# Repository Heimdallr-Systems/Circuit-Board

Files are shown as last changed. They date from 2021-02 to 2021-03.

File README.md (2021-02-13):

# Circuit-Board

Custom Power and IO board for the robot

## Folders

### CapsoneParts.3dshapes

Custom 3D models for KiCAD

### CapsstoneParts.pretty

Custom footprints for KiCAD

### optionalParts

Schematics of circuits that might be added to the main PCB

### Simulations/TINA-TI

[TINA-TI](https://www.ti.com/tool/TINA-TI) simulations used during design

### Simulations/LTspice

[LTspice](https://www.analog.com/en/design-center/design-tools-and-calculators/ltspice-simulator.html) simulations used
during design process

### TPS55288RPMR

Files used to make the TPS55288 components for KiCAD

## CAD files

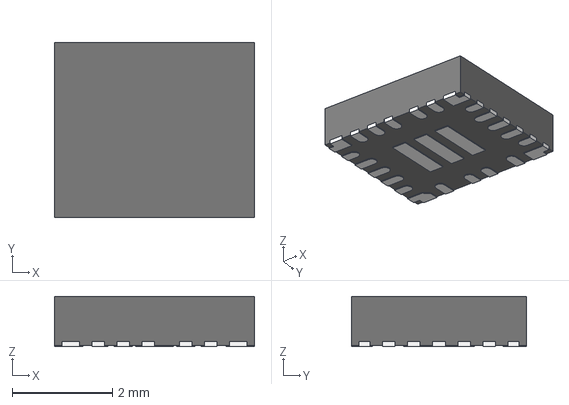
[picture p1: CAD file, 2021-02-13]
TPS55288RPMR/STEP/RPM0026A.stp
4.00 x 3.50 x 1.00 mm
FRAME
MOLD

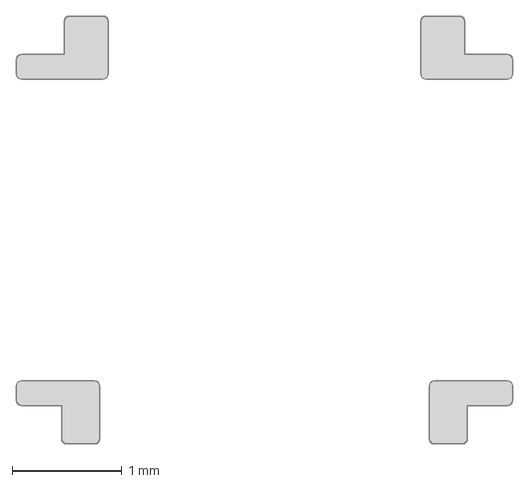
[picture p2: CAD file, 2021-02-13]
TPS55288RPMR/Cornel Stencil.dxf
4.53 x 3.90 mm

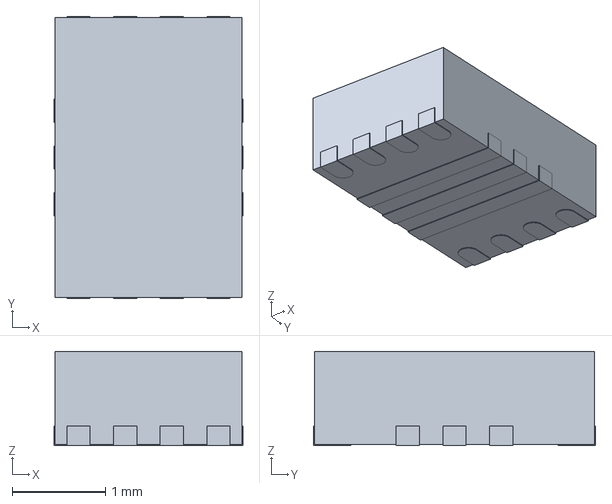
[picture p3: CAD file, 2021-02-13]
TPS55288RPMR/VQFN-11_2x3mm_P0.5mm.FCStd
2.02 x 3.02 x 1.01 mm

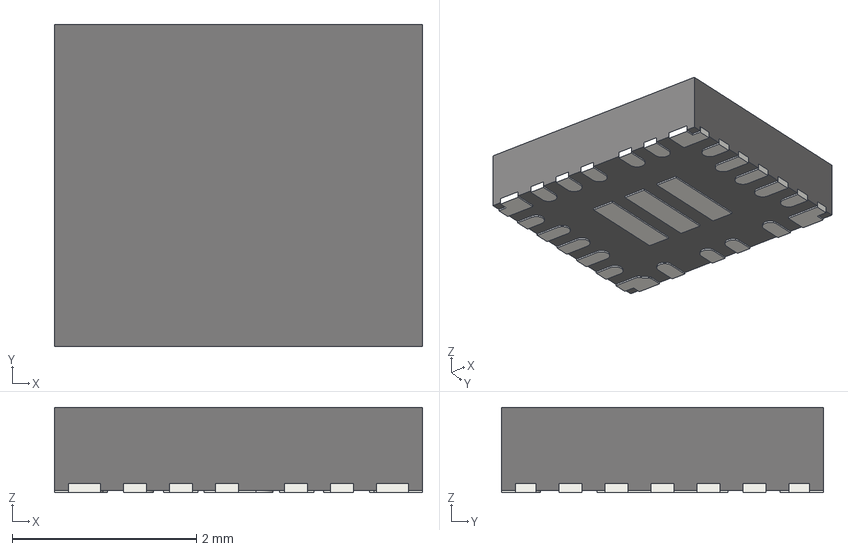
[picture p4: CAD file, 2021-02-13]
TPS55288RPMR/TPS55288RPMR.FCStd
4.00 x 3.50 x 0.925 mm
pin8
pin6
pin5
pin003
pin7
pin1
pin12
pin10
pin9
pin11
pin4
pin3
pin17
pin16
pin15
pin20
pin2
pin18
pin14
pin22
pin21
pin13
pin19
pin24
pin25
pin26

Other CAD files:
TPS55288RPMR/SolderPaste.FCStd

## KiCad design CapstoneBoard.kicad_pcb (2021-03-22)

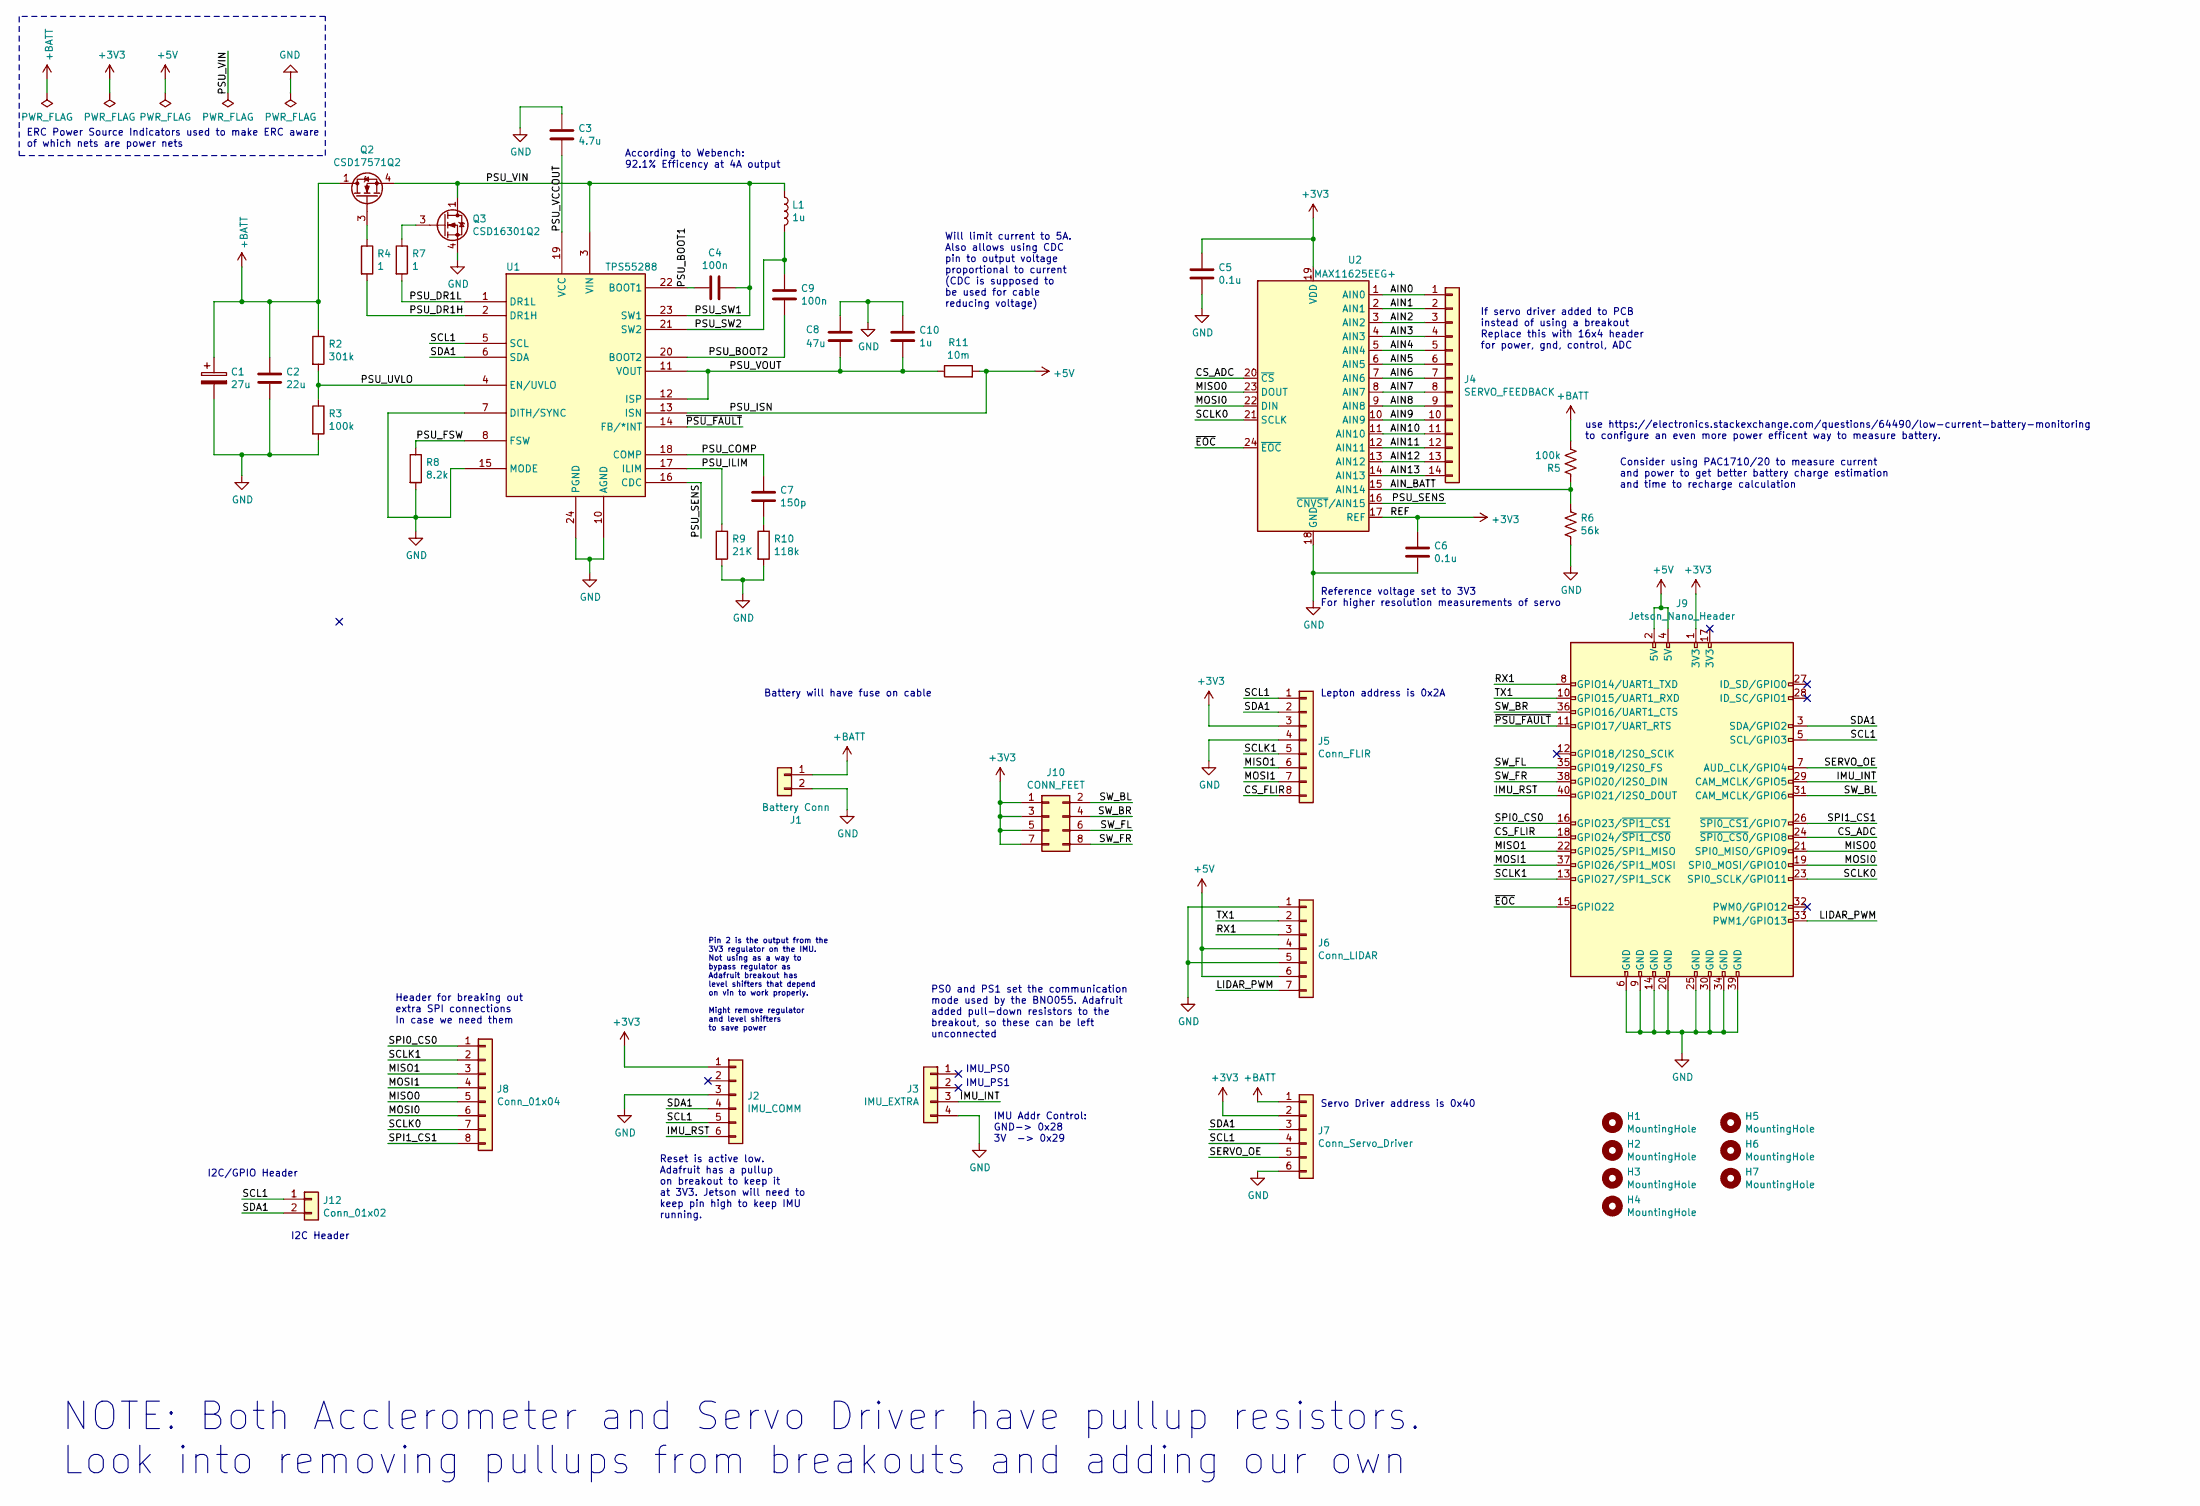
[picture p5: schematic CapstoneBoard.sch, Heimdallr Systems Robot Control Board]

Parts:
C1: 27u; C_1206_3216Metric_Pad1.33x1.80mm_HandSolder
C2: 22u; C_1206_3216Metric_Pad1.33x1.80mm_HandSolder
C3: 4.7u; C_1206_3216Metric_Pad1.33x1.80mm_HandSolder
C4, C9: 100n; C_1206_3216Metric_Pad1.33x1.80mm_HandSolder
C5, C6: 0.1u; C_0805_2012Metric_Pad1.18x1.45mm_HandSolder
C7: 150p; C_1206_3216Metric_Pad1.33x1.80mm_HandSolder
C8: 47u; C_1206_3216Metric_Pad1.33x1.80mm_HandSolder
C10: 1u; C_1206_3216Metric_Pad1.33x1.80mm_HandSolder
H1, H2, H3, H4, H5, H6, H7: MountingHole; MountingHole_2.5mm_Pad
J1: Battery Conn; wireConn2
J2: IMU_COMM; PinSocket_1x06_P2.54mm_Vertical
J3: IMU_EXTRA; PinSocket_1x04_P2.54mm_Vertical
J4: SERVO_FEEDBACK; PinHeader_1x14_P2.54mm_Vertical
J5: Conn_FLIR; PinHeader_1x08_P2.54mm_Vertical
J6: Conn_LIDAR; PinHeader_1x07_P2.54mm_Vertical
J7: Conn_Servo_Driver; PinHeader_1x06_P2.54mm_Vertical
J8: Conn_01x04; PinHeader_1x08_P2.54mm_Vertical
J9: Jetson_Nano_Header; PinHeader_2x20_P2.54mm_Vertical
J10: CONN_FEET; PinHeader_2x04_P2.54mm_Vertical
J12: Conn_01x02; PinHeader_1x02_P2.54mm_Vertical
L1: 1u; L_Vishay_IHLP-1212
Q2: CSD17571Q2; Texas_DQK
Q3: CSD16301Q2; Texas_DQK
R2: 301k; R_1206_3216Metric_Pad1.30x1.75mm_HandSolder
R3, R5: 100k; R_1206_3216Metric_Pad1.30x1.75mm_HandSolder
R4, R7: 1; R_1206_3216Metric_Pad1.30x1.75mm_HandSolder
R6: 56k; R_1206_3216Metric_Pad1.30x1.75mm_HandSolder
R8: 8.2k; R_1206_3216Metric_Pad1.30x1.75mm_HandSolder
R9: 21K; R_1206_3216Metric_Pad1.30x1.75mm_HandSolder
R10: 118k; R_1206_3216Metric_Pad1.30x1.75mm_HandSolder
R11: 10m; R_1206_3216Metric_Pad1.30x1.75mm_HandSolder
U1: TPS55288; VQFN-HR-26
U2: MAX11625EEG+; QSOP-24_3.9x8.7mm_P0.635mm

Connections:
+3V3: C5.1, C6.1, J2.1, J5.3, J7.2, J9.1 (3V3), J10.1, J10.3, J10.5, J10.7, U2.17 (REF), U2.19 (VDD)
+5V: J6.4, J6.6, J9.2 (5V), J9.4 (5V), R11.2, U1.13 (ISN)
+BATT: C1.1, C2.1, J1.1, J7.1, Q2.1 (D), Q2.2 (D), Q2.5 (D), Q2.6 (D), Q2.8 (D), R2.1, R5.2
/AIN0: J4.1, U2.1 (AIN0)
/AIN1: J4.2, U2.2 (AIN1)
/AIN2: J4.3, U2.3 (AIN2)
/AIN3: J4.4, U2.4 (AIN3)
/AIN4: J4.5, U2.5 (AIN4)
/AIN5: J4.6, U2.6 (AIN5)
/AIN6: J4.7, U2.7 (AIN6)
/AIN7: J4.8, U2.8 (AIN7)
/AIN8: J4.9, U2.9 (AIN8)
/AIN9: J4.10, U2.10 (AIN9)
/AIN10: J4.11, U2.11 (AIN10)
/AIN11: J4.12, U2.12 (AIN11)
/AIN12: J4.13, U2.13 (AIN12)
/AIN13: J4.14, U2.14 (AIN13)
/AIN_BATT: R5.1, R6.1, U2.15 (AIN14)
/CS_ADC: J9.24 (~SPI0_CS0~/GPIO8), U2.20 (~CS)
/CS_FLIR: J5.8, J9.18 (GPIO24/~SPI1_CS0~)
/IMU_INT: J3.3, J9.29 (CAM_MCLK/GPIO5)
/IMU_RST: J2.6, J9.40 (GPIO21/I2S0_DOUT)
/LIDAR_PWM: J6.7, J9.33 (PWM1/GPIO13)
/MISO0: J8.5, J9.21 (SPI0_MISO/GPIO9), U2.23 (DOUT)
/MISO1: J5.6, J8.3, J9.22 (GPIO25/SPI1_MISO)
/MOSI0: J8.6, J9.19 (SPI0_MOSI/GPIO10), U2.22 (DIN)
/MOSI1: J5.7, J8.4, J9.37 (GPIO26/SPI1_MOSI)
/PSU_BOOT1: C4.2, U1.22 (BOOT1)
/PSU_BOOT2: C9.1, U1.20 (BOOT2)
/PSU_COMP: C7.1, U1.18 (COMP)
/PSU_DR1H: R4.2, U1.2 (DR1H)
/PSU_DR1L: R7.2, U1.1 (DR1L)
/PSU_FSW: R8.1, U1.8 (FSW)
/PSU_ILIM: R9.1, U1.17 (ILIM)
/PSU_SENS: U1.16 (CDC), U2.16 (~CNVST~/AIN15)
/PSU_SW1: C4.1, L1.1, Q2.4 (S), Q2.7 (S), Q3.1 (D), Q3.2 (D), Q3.5 (D), Q3.6 (D), Q3.8 (D), U1.3 (VIN), U1.23 (SW1)
/PSU_SW2: C9.2, L1.2, U1.21 (SW2), U1.25 (SW2)
/PSU_UVLO: R2.2, R3.1, U1.4 (EN/UVLO)
/PSU_VCCOUT: C3.2, U1.19 (VCC)
/PSU_VOUT: C8.2, C10.2, R11.1, U1.11 (VOUT), U1.12 (ISP), U1.26 (VOUT)
/RX1: J6.3, J9.8 (GPIO14/UART1_TXD)
/SCL1: J2.5, J5.1, J7.4, J9.5 (SCL/GPIO3), J12.1, U1.5 (SCL)
/SCLK0: J8.7, J9.23 (SPI0_SCLK/GPIO11), U2.21 (SCLK)
/SCLK1: J5.5, J8.2, J9.13 (GPIO27/SPI1_SCK)
/SDA1: J2.4, J5.2, J7.3, J9.3 (SDA/GPIO2), J12.2, U1.6 (SDA)
/SERVO_OE: J7.5, J9.7 (AUD_CLK/GPIO4)
/SPI0_CS0: J8.1, J9.16 (GPIO23/~SPI1_CS1~)
/SPI1_CS1: J8.8, J9.26 (~SPI0_CS1~/GPIO7)
/SW_BL: J9.31 (CAM_MCLK/GPIO6), J10.2
/SW_BR: J9.36 (GPIO16/UART1_CTS), J10.4
/SW_FL: J9.35 (GPIO19/I2S0_FS), J10.6
/SW_FR: J9.38 (GPIO20/I2S0_DIN), J10.8
/TX1: J6.2, J9.10 (GPIO15/UART1_RXD)
/~EOC~: J9.15 (GPIO22), U2.24 (~EOC)
/~PSU_FAULT~: J9.11 (GPIO17/UART_RTS), U1.14 (FB/*INT)
GND: C1.2, C2.2, C3.1, C5.2, C6.2, C8.1, C10.1, J1.2, J2.3, J3.4, J5.4, J6.1, J6.5, J7.6, J9.6 (GND), J9.9 (GND), J9.14 (GND), J9.20 (GND), J9.25 (GND), J9.30 (GND), J9.34 (GND), J9.39 (GND), Q3.4 (S), Q3.7 (S), R3.2, R6.2, R8.2, R9.2, R10.2, U1.7 (DITH/SYNC), U1.9 (PGND), U1.10 (AGND), U1.15 (MODE), U1.24 (PGND), U2.18 (GND)
unnamed: C7.2, R10.1
unnamed: Q2.3 (G), R4.1
unnamed: Q3.3 (G), R7.1

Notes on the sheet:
Lepton address is 0x2A
NOTE: Both Acclerometer and Servo Driver have pullup resistors. Look into removing pullups from breakouts and adding our own
Servo Driver address is 0x40
Reset is active low. Adafruit has a pullup on breakout to keep it at 3V3. Jetson will need to keep pin high to keep IMU running.
IMU_PS0
IMU_PS1
IMU Addr Control: GND-> 0x28 3V -> 0x29
PS0 and PS1 set the communication mode used by the BNO055. Adafruit added pull-down resistors to the breakout, so these can be left unconnected
Pin 2 is the output from the 3V3 regulator on the IMU. Not using as a way to bypass regulator as Adafruit breakout has level shifters that depend on vin to work properly. Might remove regulator and level shifters to save power
Reference voltage set to 3V3 For higher resolution measurements of servo
ERC Power Source Indicators used to make ERC aware of which nets are power nets
Battery will have fuse on cable
According to Webench: 92.1% Efficency at 4A output
Will limit current to 5A. Also allows using CDC pin to output voltage proportional to current (CDC is supposed to be used for cable reducing voltage)
Header for breaking out extra SPI connections In case we need them
Consider using PAC1710/20 to measure current and power to get better battery charge estimation and time to recharge calculation
use https://electronics.stackexchange.com/questions/64490/low-current-battery-monitoring to configure an even more power efficent way to measure battery.
If servo driver added to PCB instead of using a breakout Replace this with 16x4 header for power, gnd, control, ADC
I2C/GPIO Header
I2C Header

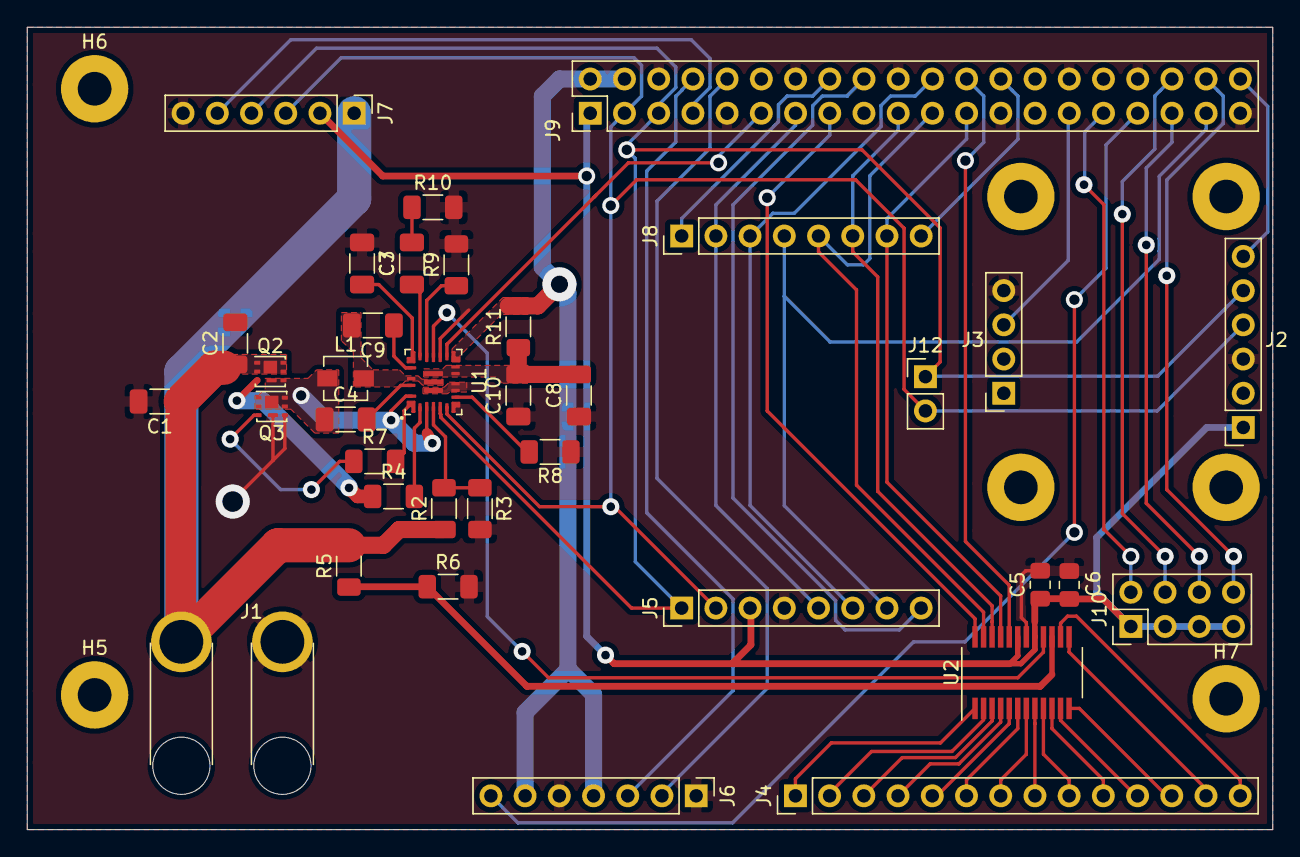
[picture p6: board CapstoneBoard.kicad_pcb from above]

Board: 2 copper layers, 92.5 x 59.6 mm, 43 parts (0 on the bottom side), 59 nets.

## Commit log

2021-02-13 Add project files
    [CapstoneBoard.kicad_pcb, CapstoneBoard.sch, Cornel Stencil.dxf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]
2021-02-16 PCB Rev 3
    [CapstoneBoard.kicad_pcb, CapstoneBoard.sch]
2021-02-26 Revision 3 completed
    [CapstoneBoard-B_Adhes.gbr, CapstoneBoard-B_CrtYd.gbr, CapstoneBoard-B_Cu.gbr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]
2021-03-22 Update board for better soldering without plated drills.
    [CapstoneBoard-B_Adhes.gbr, CapstoneBoard-B_CrtYd.gbr, CapstoneBoard-B_Cu.gbr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]
